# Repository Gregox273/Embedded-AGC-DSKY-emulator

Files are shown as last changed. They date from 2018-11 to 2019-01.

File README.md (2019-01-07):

# Embedded-AGC-DSKY-emulator
Apollo Block II AGC + DSKY emulator based on the virtualagc project (https://github.com/virtualagc/virtualagc).
The system is based on an STM32 32-bit ARM Cortex MCU, with custom PCB layout to match the position of buttons and lamps 
on the original DSKY.

### Repository Layout
* **agg-kicad:** submodule by Adam Greig containing useful KiCAD libraries, footprints and scripts.
* **binary_transcoder:** simple C program to rearrange binary output of the yaYUL assembler (see **virtualagc** 
submodule) into the order required for yaAGC emulator (also contained within **virtualagc**). Note that a pre-transcoded
binary file for Luminary099 is provided in the **firmware** directory.
* **ChibiOS:** ChibiOS RTOS submodule, developed by Giovanni Di Sirio.
* **firmware:** directory containing project source code.
* **gen-board.h:** submodule containing Python tool for generating ChibiOS 'board.h' header from a YAML file.
* **pcb:** directory containing project schematics and PCB design:
    * **agc-dsky:** KiCAD schematic and PCB files.
    * **agc-dsky.pretty:** Various component footprints.
    * **lib:** Various schematic symbols.
* **virtualagc:** Virtual Apollo Guidance Computer submodule. Contents include yaYUL (Apollo language assembler) and 
yaAGC (Apollo Guidance Computer emulator).

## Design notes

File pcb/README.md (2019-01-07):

# Hardware Notes
* STM32F072RBT6 48MHz microcontroller based on ARM Cortex-M0 core. 48MHz appears to be too slow to run the emulator and 
DSKY in realtime...
* MPU9250 IMU present on SPI2 bus (firmware can communicate with device but it has not yet been incorporated into the 
AGC emulation).
* Powered via Micro USB (<500mA current consumption at any time, so can be powered from e.g. a USB port on a computer).
* Microcontroller can be flashed over USB using DFU, or via Serial Wire Debug (SWD).
* TPS62132 switching regulator (5V USB to 3.3V) - high efficiency reduces overall current consumption.
* MCP23S08 SPI I/O expanders used to drive 7 segment displays in a multiplexed array.
  * Three displays are illuminated at a time, striking a balance between brightness and current consumption.
* Push buttons are multiplexed in a key matrix to reduce I/O pin usage.
* WS2812B LEDs arranged in a chain, allowing them to be driven from a single output pin. Each LED internally handles PWM
for red, green and blue channels.
  * Todo: drive LEDs using DMA instead of blocking the processor. This technique appears to be better documented on 
  STM32F3 and STM32F4 microcontrollers.
* UART port exposed (2.54mm header) to allow for future modifications/experimentation.

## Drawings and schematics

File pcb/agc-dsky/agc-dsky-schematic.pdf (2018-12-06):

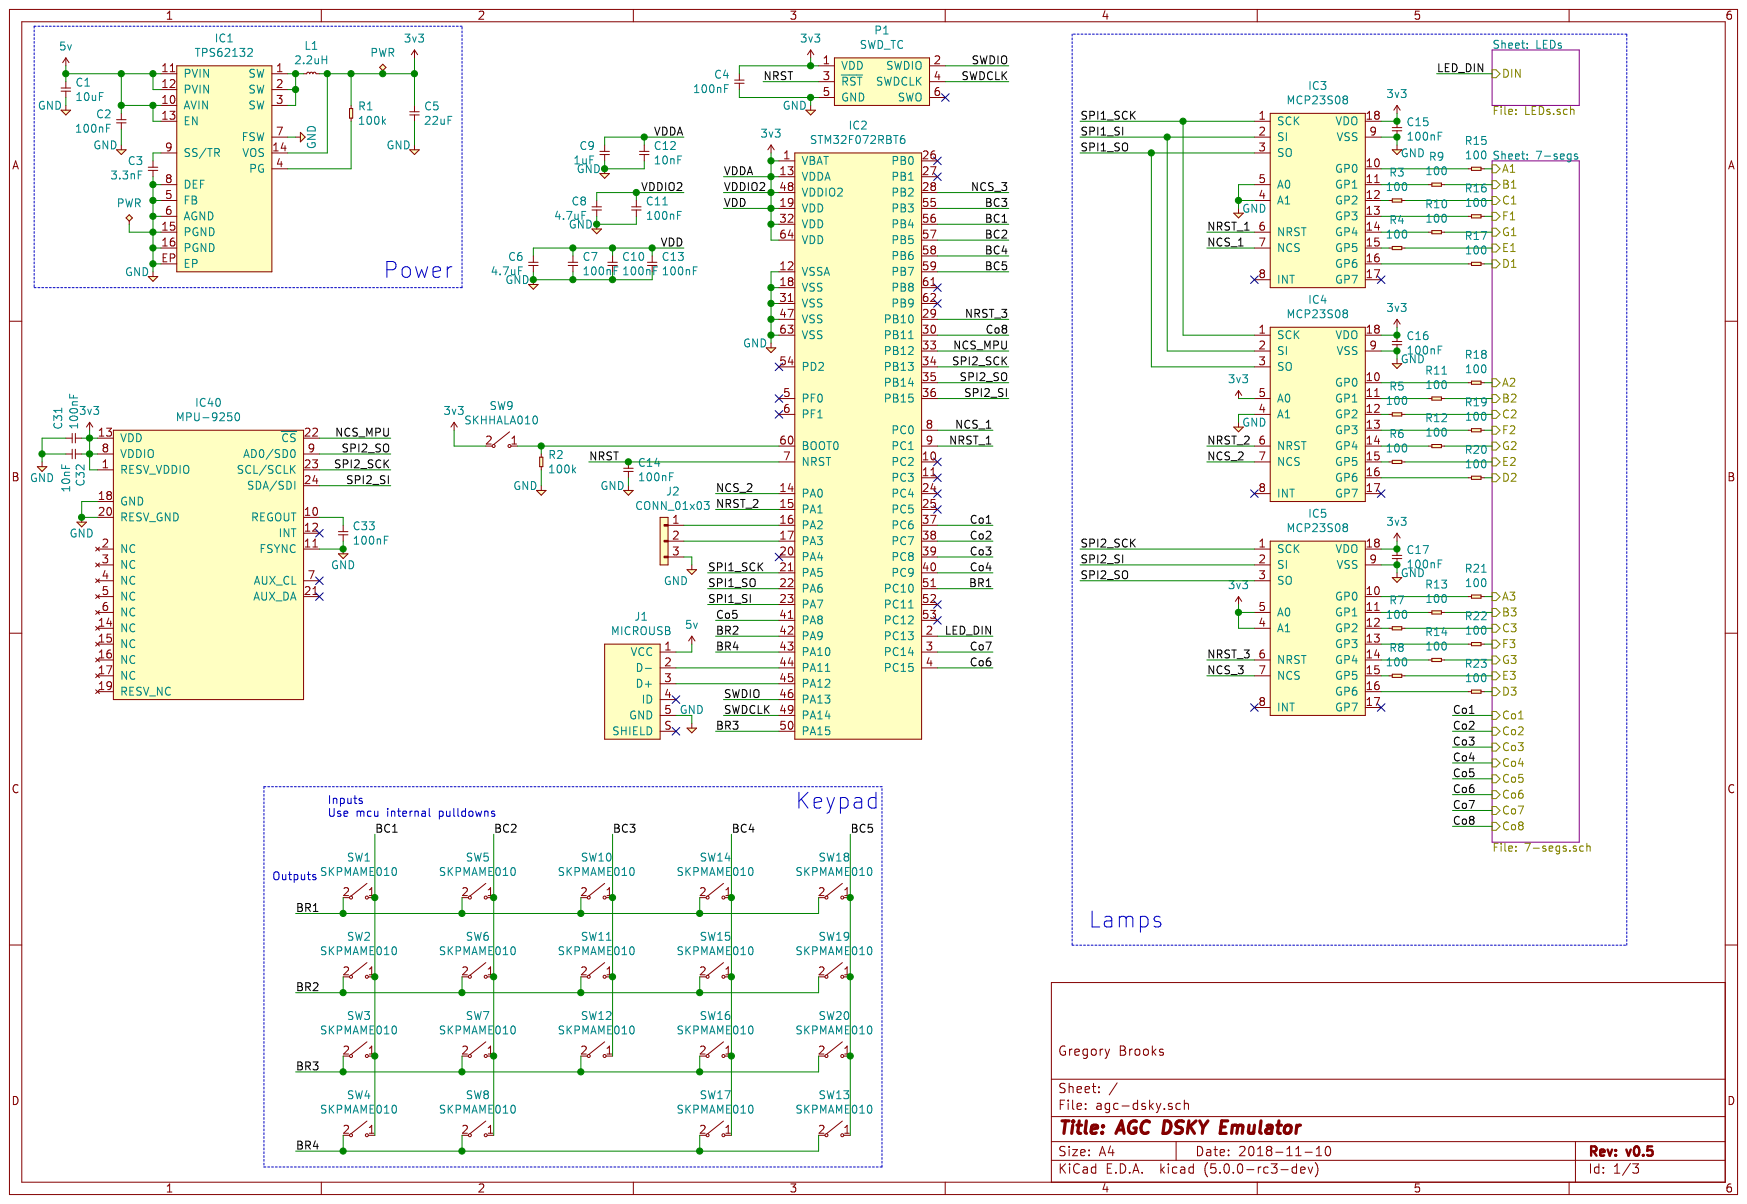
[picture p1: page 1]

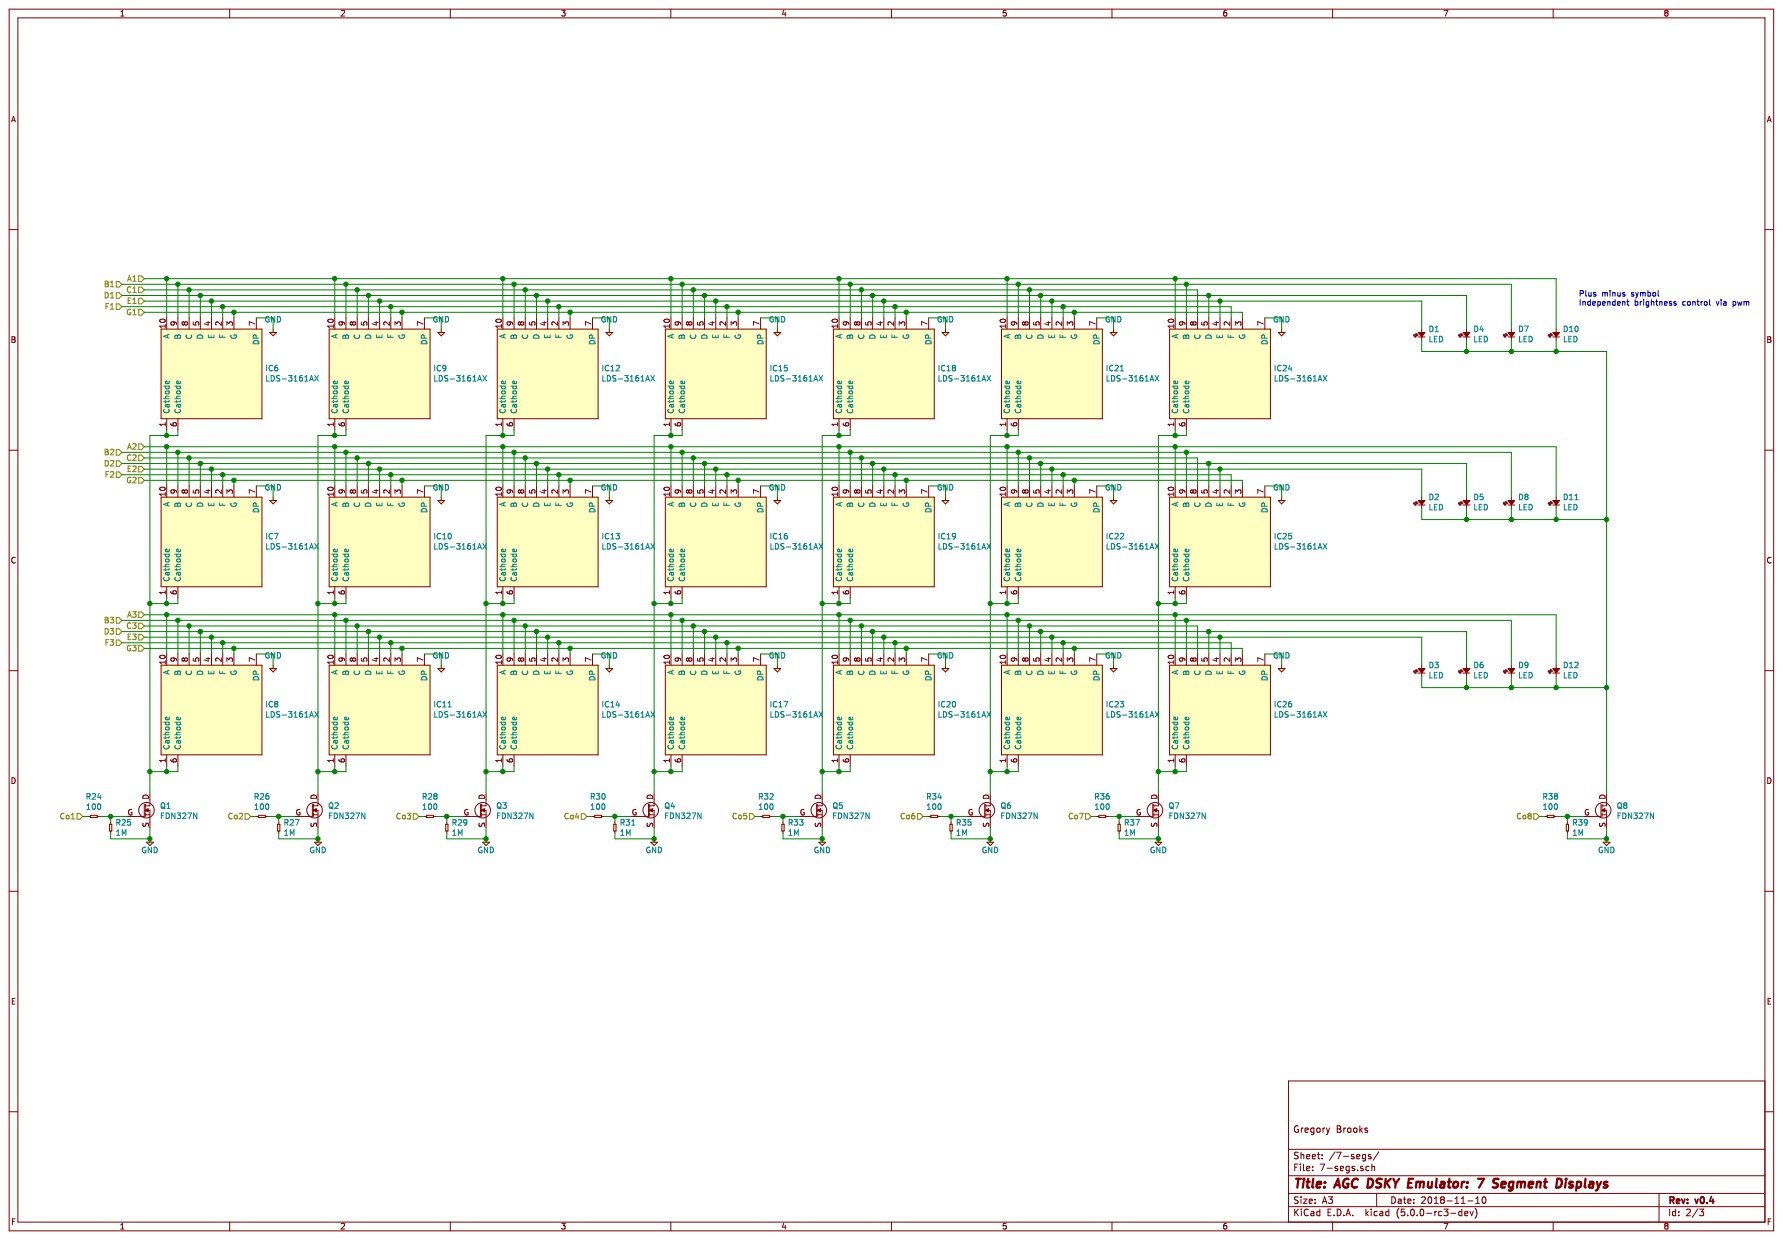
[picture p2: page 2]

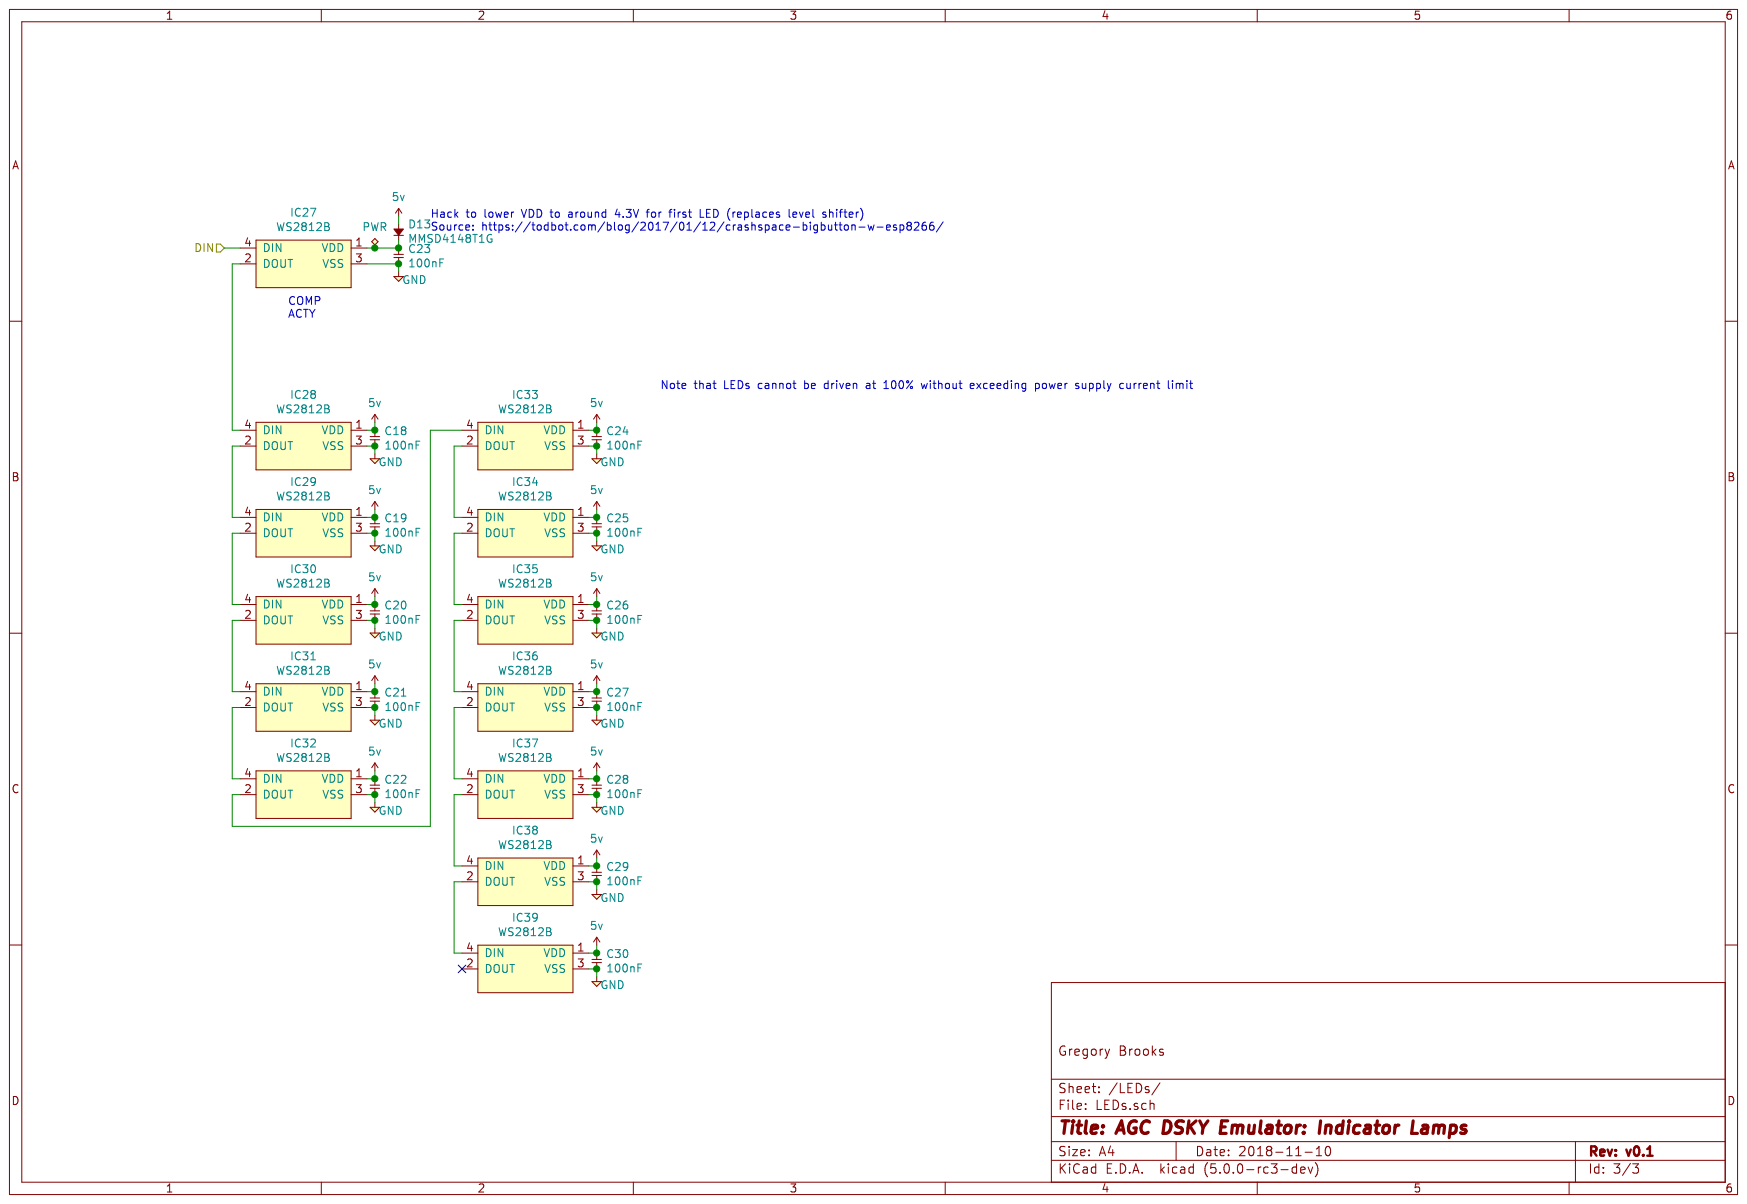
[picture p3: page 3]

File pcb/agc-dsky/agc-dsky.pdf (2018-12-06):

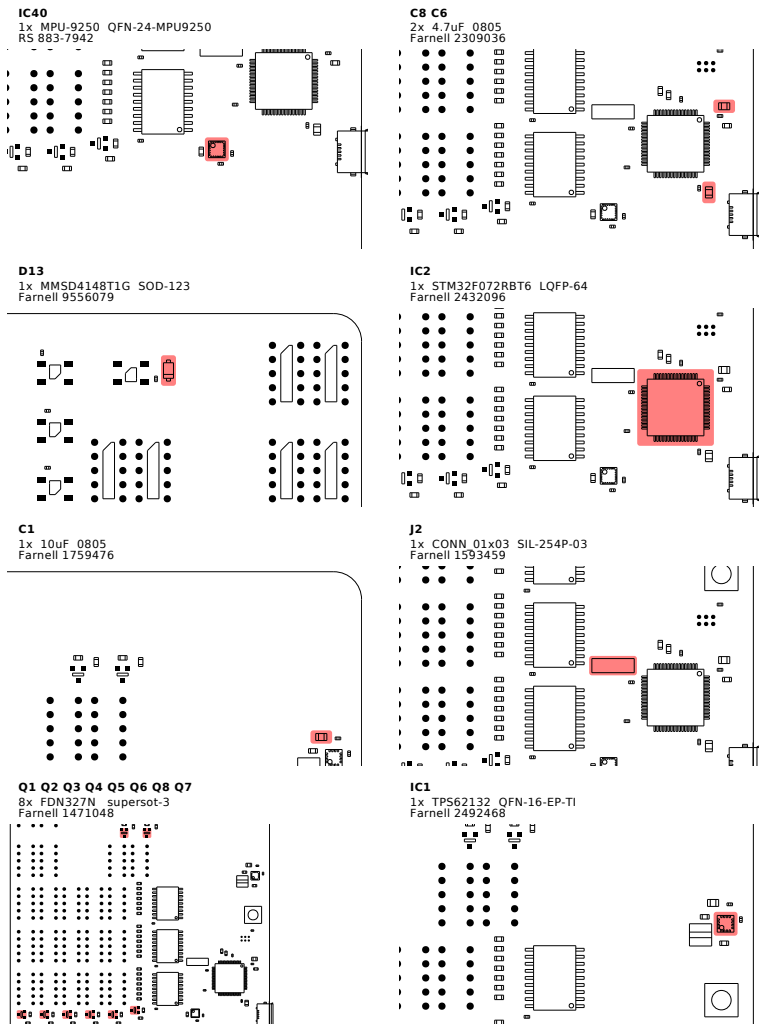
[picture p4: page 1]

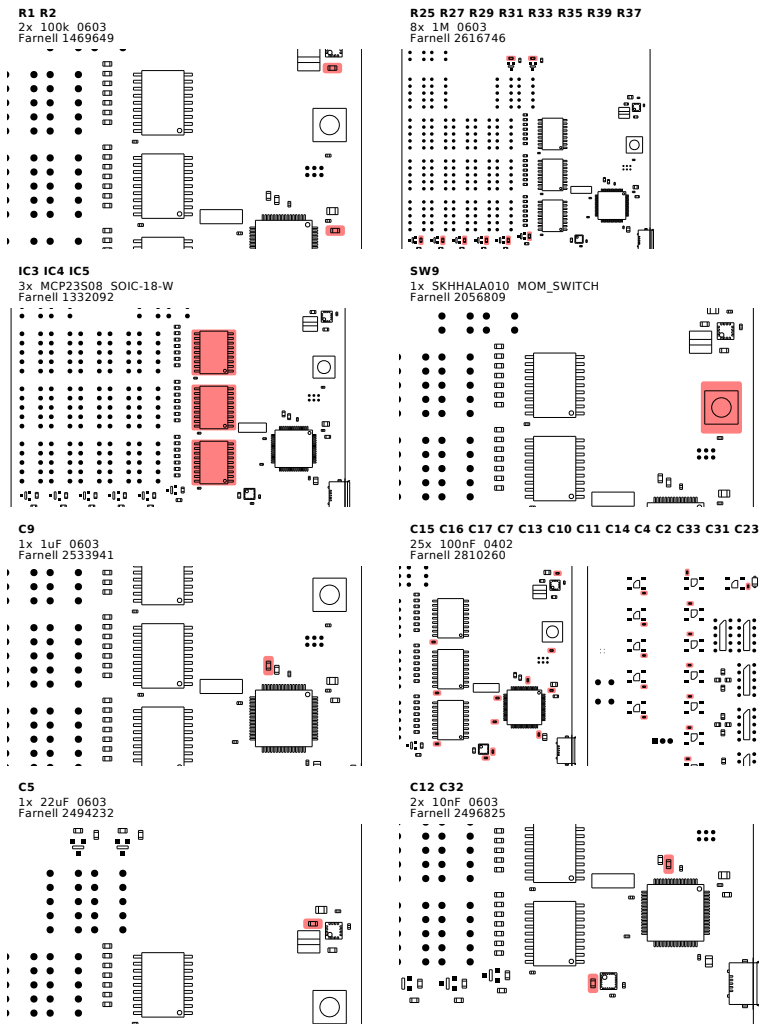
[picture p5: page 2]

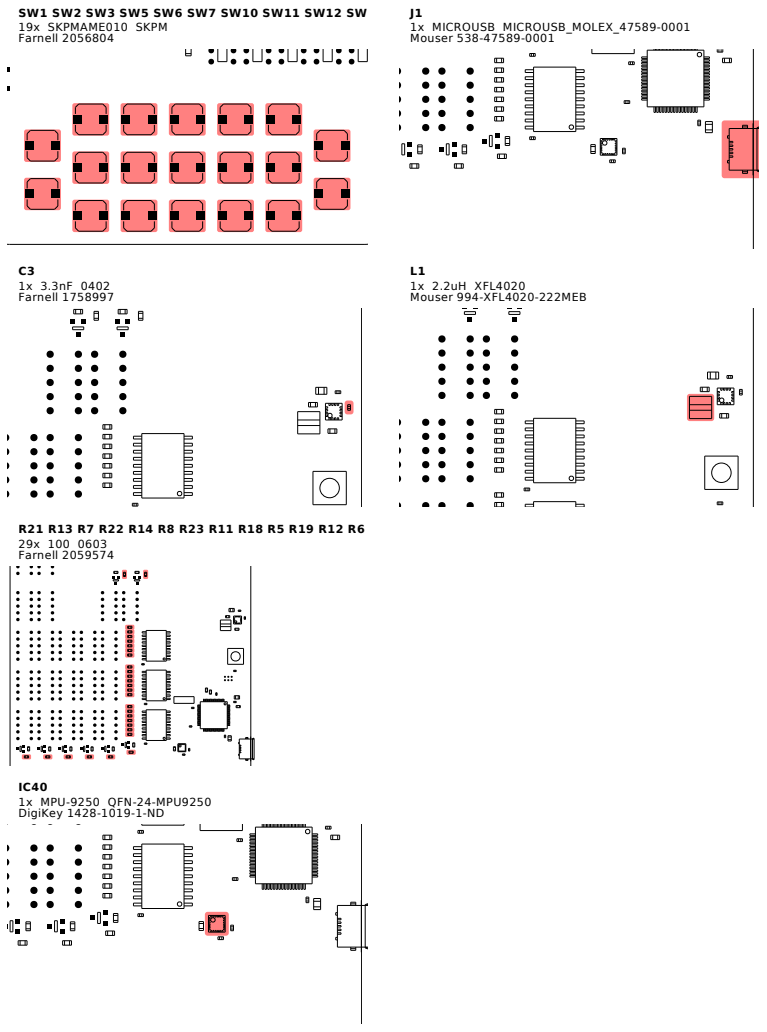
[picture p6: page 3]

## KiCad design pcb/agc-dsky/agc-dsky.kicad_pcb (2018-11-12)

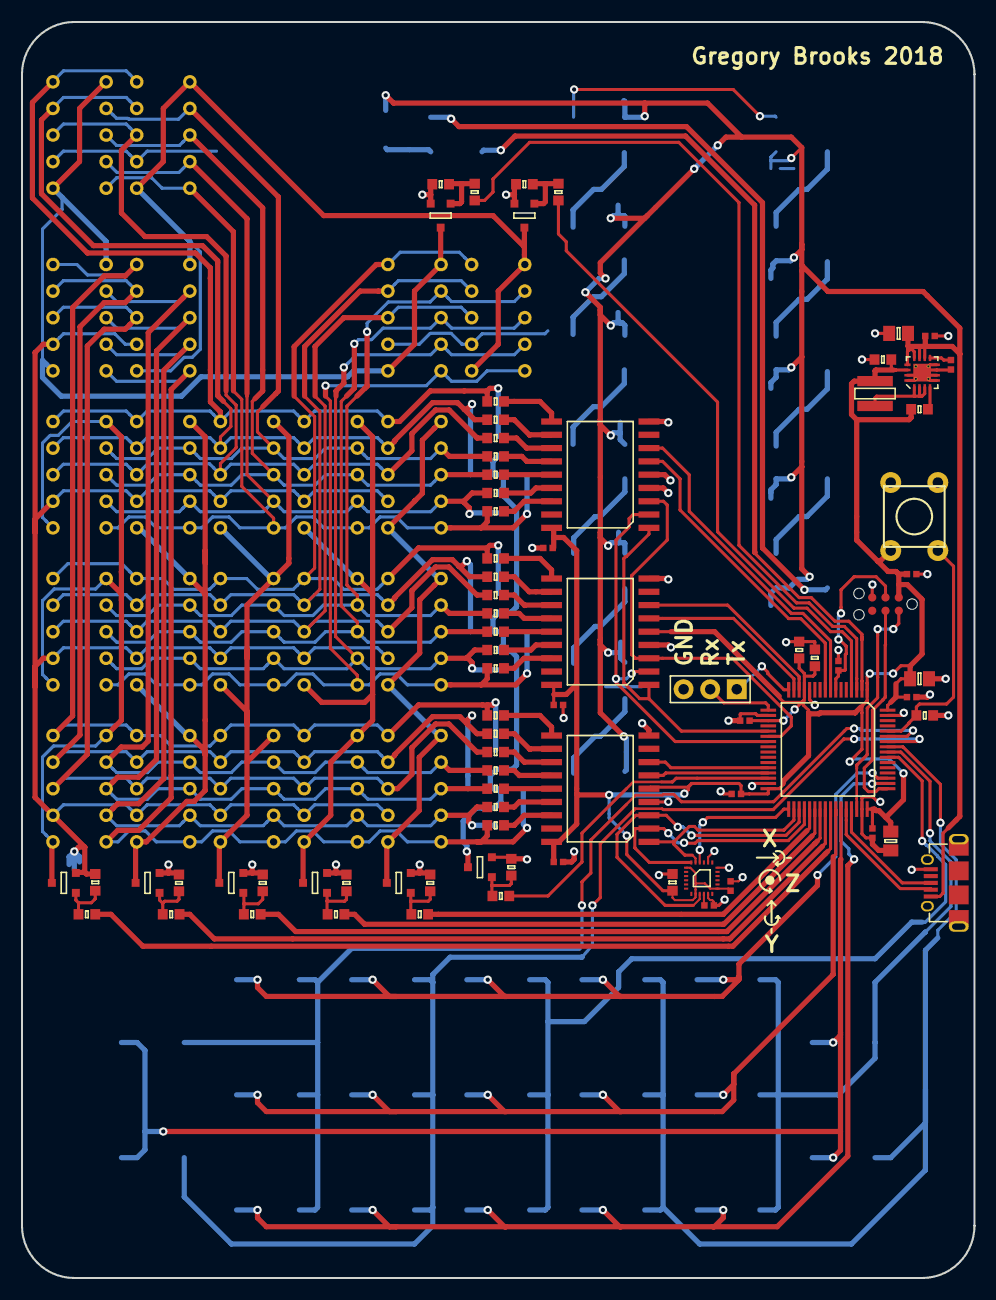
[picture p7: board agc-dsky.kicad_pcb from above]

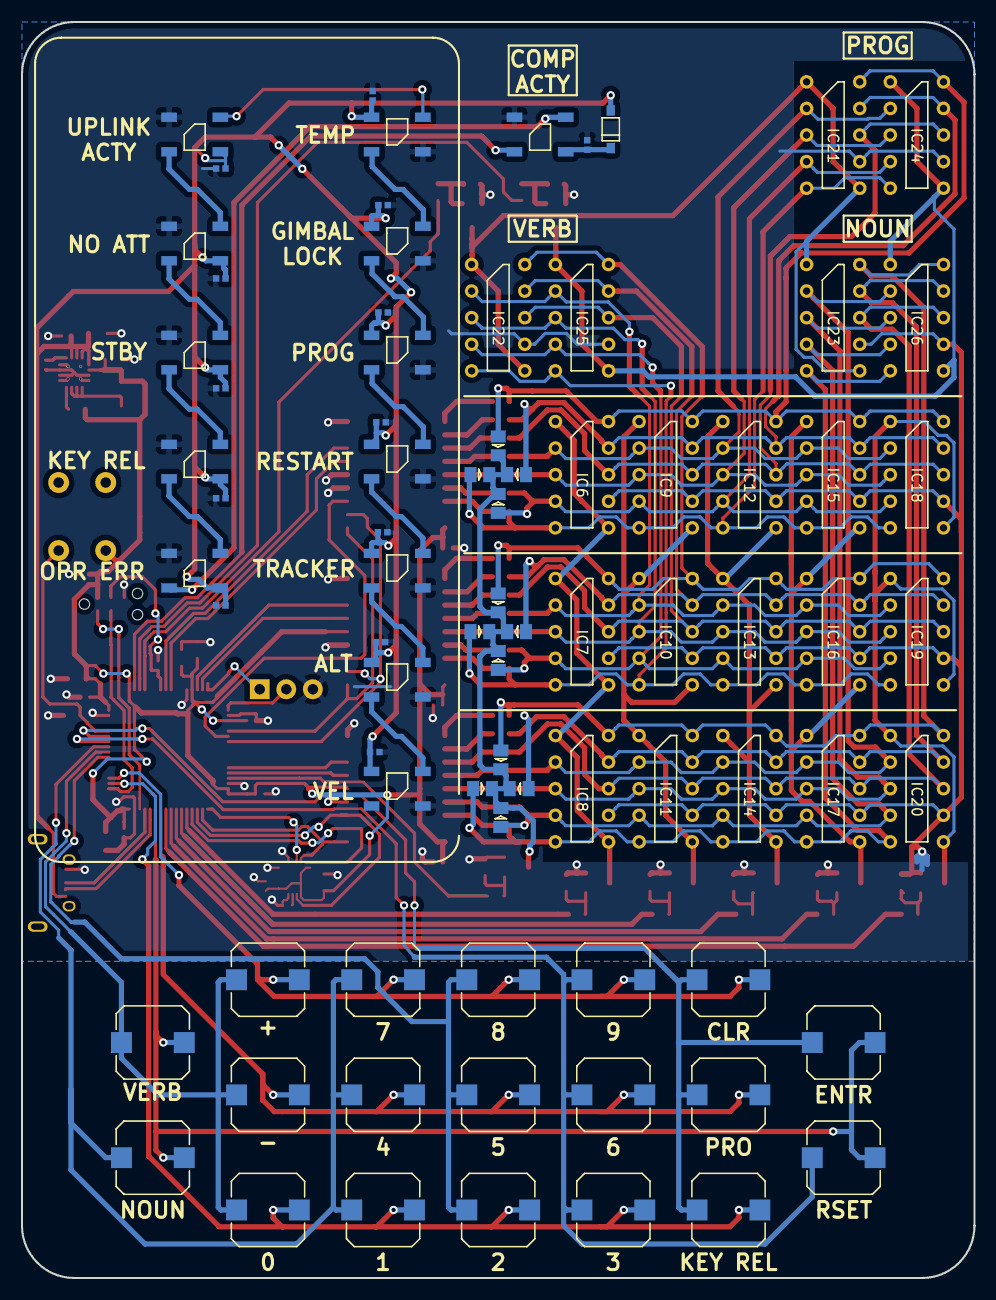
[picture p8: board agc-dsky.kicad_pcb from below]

Board: 2 copper layers, 91.0 x 120.0 mm, 157 parts (79 on the bottom side), 117 nets.

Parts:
C1: 10uF; 0805
C2, C4, C7, C10, C11, C13, C14, C15, C16, C17, C18, C19, C20, C21, C22, C23, C24, C25, C26, C27, C28, C29, C30, C31, C33: 100nF; 0402
C3: 3.3nF; 0402
C5: 22uF; 0603
C6, C8: 4.7uF; 0805
C9: 1uF; 0603
C12, C32: 10nF; 0603
D1, D2, D3, D4, D5, D6, D7, D8, D9, D10, D11, D12: LED; 0805-LED
D13: MMSD4148T1G; SOD-123
IC1: TPS62132; QFN-16-EP-TI
IC2: STM32F072RBT6; LQFP-64
IC3, IC4, IC5: MCP23S08; SOIC-18-W
IC6, IC7, IC8, IC9, IC10, IC11, IC12, IC13, IC14, IC15, IC16, IC17, IC18, IC19, IC20, IC21, IC22, IC23, IC24, IC25, IC26: LDS-3161AX
IC27, IC28, IC29, IC30, IC31, IC32, IC33, IC34, IC35, IC36, IC37, IC38, IC39: WS2812B
IC40: MPU-9250; QFN-24-MPU9250
J1: MICROUSB; MICROUSB_MOLEX_47589-0001
J2: CONN_01x03; SIL-254P-03
L1: 2.2uH; XFL4020
P1: SWD_TC; TC2030-NL
Q1, Q2, Q3, Q4, Q5, Q6, Q7, Q8: FDN327N; supersot-3
R1, R2: 100k; 0603
R3, R4, R5, R6, R7, R8, R9, R10, R11, R12, R13, R14, R15, R16, R17, R18, R19, R20, R21, R22, R23, R24, R26, R28, R30, R32, R34, R36, R38: 100; 0603
R25, R27, R29, R31, R33, R35, R37, R39: 1M; 0603
SW1, SW2, SW3, SW4, SW5, SW6, SW7, SW8, SW10, SW11, SW12, SW13, SW14, SW15, SW16, SW17, SW18, SW19, SW20: SKPMAME010; SKPM
SW9: SKHHALA010; MOM_SWITCH

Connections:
3v3: C4.1, C5.1, C6.1, C7.1, C8.1, C9.1, C10.1, C11.1, C12.1, C13.1, C15.1, C16.1, C17.1, C31.2, C32.1, IC1.14, IC2.1, IC2.13, IC2.19, IC2.32, IC2.48, IC2.64, IC3.18, IC4.5, IC4.18, IC5.4, IC5.5, IC5.18, IC40.1, IC40.8, IC40.13, L1.2, P1.1, R1.1, SW9.2
5v: C1.1, C2.1, C18.1, C19.1, C20.1, C21.1, C22.1, C24.1, C25.1, C26.1, C27.1, C28.1, C29.1, C30.1, D13.2, IC1.10, IC1.11, IC1.12, IC1.13, IC28.1, IC29.1, IC30.1, IC31.1, IC32.1, IC33.1, IC34.1, IC35.1, IC36.1, IC37.1, IC38.1, IC39.1, J1.1
/7-segs/A1: D10.2, IC6.10, IC9.10, IC12.10, IC15.10, IC18.10, IC21.10, IC24.10, R15.2
/7-segs/A2: D11.2, IC7.10, IC10.10, IC13.10, IC16.10, IC19.10, IC22.10, IC25.10, R18.2
/7-segs/A3: D12.2, IC8.10, IC11.10, IC14.10, IC17.10, IC20.10, IC23.10, IC26.10, R21.2
/7-segs/B1: D7.2, IC6.9, IC9.9, IC12.9, IC15.9, IC18.9, IC21.9, IC24.9, R9.2
/7-segs/B2: D8.2, IC7.9, IC10.9, IC13.9, IC16.9, IC19.9, IC22.9, IC25.9, R11.2
/7-segs/B3: D9.2, IC8.9, IC11.9, IC14.9, IC17.9, IC20.9, IC23.9, IC26.9, R13.2
/7-segs/C1: IC6.8, IC9.8, IC12.8, IC15.8, IC18.8, IC21.8, IC24.8, R3.2
/7-segs/C2: IC7.8, IC10.8, IC13.8, IC16.8, IC19.8, IC22.8, IC25.8, R5.2
/7-segs/C3: IC8.8, IC11.8, IC14.8, IC17.8, IC20.8, IC23.8, IC26.8, R7.2
/7-segs/D1: D4.2, IC6.5, IC9.5, IC12.5, IC15.5, IC18.5, IC21.5, IC24.5, R17.2
/7-segs/D2: D5.2, IC7.5, IC10.5, IC13.5, IC16.5, IC19.5, IC22.5, IC25.5, R20.2
/7-segs/D3: D6.2, IC8.5, IC11.5, IC14.5, IC17.5, IC20.5, IC23.5, IC26.5, R23.2
/7-segs/E1: D1.2, IC6.4, IC9.4, IC12.4, IC15.4, IC18.4, IC21.4, IC24.4, R4.2
/7-segs/E2: D2.2, IC7.4, IC10.4, IC13.4, IC16.4, IC19.4, IC22.4, IC25.4, R6.2
/7-segs/E3: D3.2, IC8.4, IC11.4, IC14.4, IC17.4, IC20.4, IC23.4, IC26.4, R8.2
/7-segs/F1: IC6.2, IC9.2, IC12.2, IC15.2, IC18.2, IC21.2, IC24.2, R16.2
/7-segs/F2: IC7.2, IC10.2, IC13.2, IC16.2, IC19.2, IC22.2, IC25.2, R19.2
/7-segs/F3: IC8.2, IC11.2, IC14.2, IC17.2, IC20.2, IC23.2, IC26.2, R22.2
/7-segs/G1: IC6.3, IC9.3, IC12.3, IC15.3, IC18.3, IC21.3, IC24.3, R10.2
/7-segs/G2: IC7.3, IC10.3, IC13.3, IC16.3, IC19.3, IC22.3, IC25.3, R12.2
/7-segs/G3: IC8.3, IC11.3, IC14.3, IC17.3, IC20.3, IC23.3, IC26.3, R14.2
/BC1: IC2.56, SW1.1, SW2.1, SW3.1, SW4.1
/BC2: IC2.57, SW5.1, SW6.1, SW7.1, SW8.1
/BC3: IC2.55, SW10.1, SW11.1, SW12.1
/BC4: IC2.58, SW14.1, SW15.1, SW16.1, SW17.1
/BC5: IC2.59, SW13.1, SW18.1, SW19.1, SW20.1
/BR1: IC2.51, SW1.2, SW5.2, SW10.2, SW14.2, SW18.2
/BR2: IC2.42, SW2.2, SW6.2, SW11.2, SW15.2, SW19.2
/BR3: IC2.50, SW3.2, SW7.2, SW12.2, SW16.2, SW20.2
/BR4: IC2.43, SW4.2, SW8.2, SW13.2, SW17.2
/Co1: IC2.37, R24.1
/Co2: IC2.38, R26.1
/Co3: IC2.39, R28.1
/Co4: IC2.40, R30.1
/Co5: IC2.41, R32.1
/Co6: IC2.4, R34.1
/Co7: IC2.3, R36.1
/Co8: IC2.30, R38.1
/LED_DIN: IC2.2, IC27.4
/NCS_1: IC2.8, IC3.7
/NCS_2: IC2.14, IC4.7
/NCS_3: IC2.28, IC5.7
/NCS_MPU: IC2.33, IC40.22
/NRST: C14.1, IC2.7, P1.3
/NRST_1: IC2.9, IC3.6
/NRST_2: IC2.15, IC4.6
/NRST_3: IC2.29, IC5.6
/SPI1_SCK: IC2.21, IC3.1, IC4.1
/SPI1_SI: IC2.23, IC3.2, IC4.2
/SPI1_SO: IC2.22, IC3.3, IC4.3
/SPI2_SCK: IC2.34, IC5.1, IC40.23
/SPI2_SI: IC2.36, IC5.2, IC40.24
/SPI2_SO: IC2.35, IC5.3, IC40.9
/SWDCLK: IC2.49, P1.4
/SWDIO: IC2.46, P1.2
GND: C1.2, C2.2, C3.1, C4.2, C5.2, C6.2, C7.2, C8.2, C9.2, C10.2, C11.2, C12.2, C13.2, C14.2, C15.2, C16.2, C17.2, C18.2, C19.2, C20.2, C21.2, C22.2, C23.2, C24.2, C25.2, C26.2, C27.2, C28.2, C29.2, C30.2, C31.1, C32.2, C33.2, IC1.5, IC1.6, IC1.7, IC1.8, IC1.15, IC1.16, IC1.EP, IC2.12, IC2.18, IC2.31, IC2.47, IC2.63, IC3.4, IC3.5, IC3.9, IC4.4, IC4.9, IC5.9, IC6.7, IC7.7, IC8.7, IC9.7, IC10.7, IC11.7, IC12.7, IC13.7, IC14.7, IC15.7, IC16.7, IC17.7, IC18.7, IC19.7, IC20.7, IC21.7, IC22.7, IC23.7, IC24.7, IC25.7, IC26.7, IC27.3, IC28.3, IC29.3, IC30.3, IC31.3, IC32.3, IC33.3, IC34.3, IC35.3, IC36.3, IC37.3, IC38.3, IC39.3, IC40.11, IC40.18, IC40.20, J1.5, J2.3, P1.5, Q1.S, Q2.S, Q3.S, Q4.S, Q5.S, Q6.S, Q7.S, Q8.S, R2.2, R25.2, R27.2, R29.2, R31.2, R33.2, R35.2, R37.2, R39.2
unnamed: C3.2, IC1.9
unnamed: C23.1, D13.1, IC27.1
unnamed: C33.1, IC40.10
unnamed: D1.1, D2.1, D3.1, D4.1, D5.1, D6.1, D7.1, D8.1, D9.1, D10.1, D11.1, D12.1, Q8.D
unnamed: IC1.1, IC1.2, IC1.3, L1.1
unnamed: IC1.4, R1.2
unnamed: IC2.16, J2.1
unnamed: IC2.17, J2.2
unnamed: IC2.44, J1.2
unnamed: IC2.45, J1.3
unnamed: IC2.60, R2.1, SW9.1
unnamed: IC3.10, R15.1
unnamed: IC3.11, R9.1
unnamed: IC3.12, R3.1
unnamed: IC3.13, R16.1
unnamed: IC3.14, R10.1
unnamed: IC3.15, R4.1
unnamed: IC3.16, R17.1
unnamed: IC4.10, R18.1
unnamed: IC4.11, R11.1
unnamed: IC4.12, R5.1
unnamed: IC4.13, R19.1
unnamed: IC4.14, R12.1
unnamed: IC4.15, R6.1
unnamed: IC4.16, R20.1
unnamed: IC5.10, R21.1
unnamed: IC5.11, R13.1
unnamed: IC5.12, R7.1
unnamed: IC5.13, R22.1
unnamed: IC5.14, R14.1
unnamed: IC5.15, R8.1
unnamed: IC5.16, R23.1
unnamed: IC6.1, IC6.6, IC7.1, IC7.6, IC8.1, IC8.6, Q1.D
unnamed: IC9.1, IC9.6, IC10.1, IC10.6, IC11.1, IC11.6, Q2.D
unnamed: IC12.1, IC12.6, IC13.1, IC13.6, IC14.1, IC14.6, Q3.D
unnamed: IC15.1, IC15.6, IC16.1, IC16.6, IC17.1, IC17.6, Q4.D
unnamed: IC18.1, IC18.6, IC19.1, IC19.6, IC20.1, IC20.6, Q5.D
unnamed: IC21.1, IC21.6, IC22.1, IC22.6, IC23.1, IC23.6, Q6.D
unnamed: IC24.1, IC24.6, IC25.1, IC25.6, IC26.1, IC26.6, Q7.D
unnamed: IC27.2, IC28.4
unnamed: IC28.2, IC29.4
unnamed: IC29.2, IC30.4
unnamed: IC30.2, IC31.4
unnamed: IC31.2, IC32.4
unnamed: IC32.2, IC33.4
unnamed: IC33.2, IC34.4
unnamed: IC34.2, IC35.4
unnamed: IC35.2, IC36.4
unnamed: IC36.2, IC37.4
unnamed: IC37.2, IC38.4
unnamed: IC38.2, IC39.4
unnamed: Q1.G, R24.2, R25.1
unnamed: Q2.G, R26.2, R27.1
unnamed: Q3.G, R28.2, R29.1
unnamed: Q4.G, R30.2, R31.1
unnamed: Q5.G, R32.2, R33.1
unnamed: Q6.G, R34.2, R35.1
unnamed: Q7.G, R36.2, R37.1
unnamed: Q8.G, R38.2, R39.1

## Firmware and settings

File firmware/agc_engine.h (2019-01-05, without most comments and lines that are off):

#ifndef AGC_SOCKET_ENABLED
#ifdef __cplusplus
extern "C" {
#endif
#define AGC_ENGINE_H
#define NULL ((void *) 0)
#ifdef WIN32
typedef short int16_t;
typedef signed char int8_t;
typedef unsigned char uint8_t; // 20170326
typedef unsigned int uint32_t; // 20170326
typedef unsigned short uint16_t; // 20170329
#ifdef __MINGW32__
typedef unsigned long long uint64_t;
#else
typedef unsigned __int64 uint64_t;
#endif
#elif defined (__embedded__)
#include <stdint.h>
#elif defined (SDCC)
typedef int int16_t;
typedef signed char int8_t;
typedef unsigned uint16_t;
extern long random (void);
#else // WIN32
#include <stdint.h>
#endif // WIN32
#ifdef WIN32
#define SOCKET_BROKEN 1
#else
#define SOCKET_ERROR -1
#define SOCKET_BROKEN (errno == EPIPE)
#endif
#define MAX_SYM_DUMP 25
#define MAX_FILE_DUMP 25
#define AGC_PER_SECOND ((1024000 + 6) / 12)
#define REG16 3
#define RegA 00
#define RegL 01
#define RegQ 02
#define RegEB 03
#define RegFB 04
#define RegZ 05
#define RegBB 06
#define RegZERO 07
#define RegARUPT 010
#define RegLRUPT 011
#define RegQRUPT 012
#define RegZRUPT 015
#define RegBBRUPT 016
#define RegBRUPT 017
#define RegCYR 020
#define RegSR 021
#define RegCYL 022
#define RegEDOP 023
#define RegCOUNTER 024
#define RegTIME2 024
#define RegTIME1 025
#define RegTIME3 026
#define RegTIME4 027
#define RegTIME5 030
#define RegTIME6 031
#define RegCDUX 032
#define RegCDUY 033
#define RegCDUZ 034
#define RegOPTY 035
#define RegOPTX 036
#define RegPIPAX 037
#define RegPIPAY 040
#define RegPIPAZ 041
#define RegRHCP 042
#define RegRHCY 043
#define RegRHCR 044
#define RegINLINK 045
#define RegRNRAD 046
#define RegGYROCTR 047
#define RegCDUXCMD 050
#define RegCDUYCMD 051
#define RegCDUZCMD 052
#define RegOPTYCMD 053
#define RegOPTXCMD 054
#define RegOUTLINK 057
#define RegALTM 060
#define RegRAM 060
#define RegCORE 04000
#define RegEND 0120000
#define NUM_CHANNELS 512
#define ChanSCALER2 03
#define ChanSCALER1 04
#define ChanS 07
#define CH77_PARITY_FAIL    000001
#define CH77_TC_TRAP        000004
#define CH77_RUPT_LOCK      000010
#define CH77_NIGHT_WATCHMAN 000020
#define DSKY_AGC_WARN 000001
#define DSKY_TEMP     000010
#define DSKY_KEY_REL  000020
#define DSKY_VN_FLASH 000040
#define DSKY_OPER_ERR 000100
#define DSKY_RESTART  000200
#define DSKY_STBY     000400
#define DSKY_EL_OFF   001000
#define NUM_INTERRUPT_TYPES 10
#define MAX_DOWNLINK_LIST 260
#define DEFAULT_SWIDTH 79
#define DEFAULT_SHEIGHT 42
#define SWIDTH 160
#define SHEIGHT 100
#define DL_CM_POWERED_LIST 0
#define DL_LM_ORBITAL_MANEUVERS 1
#define DL_CM_COAST_ALIGN 2
#define DL_LM_COAST_ALIGN 3
#define DL_CM_RENDEZVOUS_PRETHRUST 4
#define DL_LM_RENDEZVOUS_PRETHRUST 5
#define DL_CM_PROGRAM_22 6
#define DL_LM_DESCENT_ASCENT 7
#define DL_LM_LUNAR_SURFACE_ALIGN 8
#define DL_CM_ENTRY_UPDATE 9
#define DL_LM_AGS_INITIALIZATION_UPDATE 10
typedef enum {
  FMT_SP, FMT_DP, FMT_OCT, FMT_2OCT, FMT_DEC, FMT_2DEC, FMT_USP
} Format_t;
typedef void Swrite_t (void);
typedef char *Sformat_t (int IndexIntoList, int Scale, Format_t Format);
typedef struct {
  int IndexIntoList;	// if -1, then is a spacer.
  char Name[65];
  int Scale;
  Format_t Format;
  Sformat_t *Formatter;
  int Row;		// If 0,0, then just "next" position.
  int Col;
} FieldSpec_t;
typedef struct {
  char Title[SWIDTH + 1];
  FieldSpec_t FieldSpecs[MAX_DOWNLINK_LIST];
} DownlinkListSpec_t;
typedef void ProcessDownlinkList_t (const DownlinkListSpec_t *Spec);
typedef struct
{
  uint64_t  CycleCounter;
  int16_t Erasable[8][0400];	// Banks 0,1,2 are "unswitched erasable".
  uint32_t Parities[40*(02000/32)];
  int16_t InputChannel[NUM_CHANNELS];
  int16_t OutputChannel7;
  int16_t OutputChannel10[16];
  int16_t IndexValue;
  int8_t InterruptRequests[1 + NUM_INTERRUPT_TYPES];	// 0-index not used.
  unsigned ExtraCode:1;		// Set by the "Extend" instruction.
  unsigned AllowInterrupt:1;
  unsigned InIsr:1;		// Set when in an ISR, reset when in normal code.
  unsigned SubstituteInstruction:1;	// Use BBRUPT register.
  unsigned PendFlag:1;		// Multi-MCT instruction pending.
  unsigned PendDelay:3;		// Countdown to pending instruction.
  unsigned ExtraDelay:3;	// ... and extra, for special cases.
  unsigned DownruptTimeValid:1;	// Set if the DownruptTime field is valid.
  unsigned NightWatchman:1;     // Set when Night Watchman is watching. Cleared by accessing address 67.
  unsigned NightWatchmanTripped:1; // Set when Night Watchman has been tripped and its CH77 bit is being asserted.
  unsigned RuptLock:1;          // Set when rupts are being watched. Cleared by executing any non-ISR instruction
  unsigned NoRupt:1;            // Set when rupts are being watched. Cleared by executing any ISR instruction
  unsigned TCTrap:1;            // Set when TC is being watched. Cleared by executing any non-TC/TCF instruction
  unsigned NoTC:1;              // Set when TC is being watched. Cleared by executing TC or TCF
  unsigned Standby:1;           // Set while the computer is in standby mode.
  unsigned SbyPressed:1;        // Set while PRO is being held down; cleared by releasing PRO
  unsigned SbyStillPressed:1;   // Set upon entry to standby, until PRO is released
  unsigned ParityFail:1;        // Set when a parity failure is encountered accessing memory (in yaAGC, just hitting banks 44+)
  unsigned CheckParity:1;       // Enable parity checking for fixed memory.
  unsigned RestartLight:1;      // The present state of the RESTART light
  unsigned TookBZF:1;           // Flag for having just taken a BZF branch, used for simulation of a TC Trap hardware bug
  unsigned TookBZMF:1;          // Flag for having just taken a BZMF branch, used for simulation of a TC Trap hardware bug
  unsigned GeneratedWarning:1;  // Whether there is a pending input to the warning filter
  unsigned Trap31A:1;           // Enable flag for Trap 31A
  unsigned Trap31B:1;           // Enable flag for Trap 31B
  unsigned Trap32:1;            // Enable flag for Trap 32
  uint32_t WarningFilter;       // Current voltage of the AGC warning filter
  uint64_t  DownruptTime;	// Time when next DOWNRUPT occurs.
  int Downlink;
  int NextZ;                    // Next value for the Z register
  int ScalerCounter;            // Counter to keep track of scaler increment timing
  int ChannelRoutineCount;      // Counter to keep track of channel interface routine timing
  unsigned DskyTimer;           // Timer for DSKY-related timing
  unsigned DskyFlash;           // DSKY flash counter (0 = flash occurring)
  unsigned DskyChannel163;      // Copy of the fake DSKY channel 163
  void *agc_clientdata;
} agc_t;
#define MAX_DEBUG_RULES 256
typedef struct
{
  int KeyCode;
  int Channel;
  int Value;
  char Logic;
} DebugRule_t;
#ifdef AGC_ENGINE_C
int DebugDsky = 0;
int InhibitAlarms = 0;
int NumDebugRules = 0;
DebugRule_t DebugRules[MAX_DEBUG_RULES];
#else
extern int DebugDsky;
extern int InhibitAlarms;
extern int NumDebugRules;
extern DebugRule_t DebugRules[MAX_DEBUG_RULES];
extern int initializeSunburst37;
#endif
#define MAX_BACKTRACE_POINTS 100
#define BACKTRACES_PER_LINE 5
typedef struct {
  uint64_t  CycleCounter;
  int16_t Erasable[8][0400];	// Banks 0,1,2 are "unswitched erasable".
  int16_t InputChannel[NUM_CHANNELS];
  int16_t OutputChannel7;
  int16_t OutputChannel10[16];
  int16_t IndexValue;
  int8_t InterruptRequests[1 + NUM_INTERRUPT_TYPES];
  int8_t DueToInterrupt;	// Indicates interrupt type causing jump (0 if not).
  unsigned ExtraCode:1;		// Set by the "Extend" instruction.
  unsigned AllowInterrupt:1;	// Set when interrupts are enabled.
  unsigned InIsr:1;		// Set when in an ISR, reset when in normal code.
  unsigned SubstituteInstruction:1;	// Use BBRUPT register.
} BacktracePoint_t;
typedef struct
{
  int Socket;
  unsigned char Packet[4];
  int Size;
  int ChannelMasks[256];
} Client_t;
#define DEFAULT_MAX_CLIENTS 10
#ifdef AGC_ENGINE_C
int DebugMode = 0;
int SingleStepCounter = -2;		// -2 when not in --debug mode.
int BacktraceInitialized = 0;		// Becomes -1 on error.
BacktracePoint_t *BacktracePoints = NULL;
int BacktraceNextAdd = 0;
int BacktraceCount = 0;
int MAX_CLIENTS = DEFAULT_MAX_CLIENTS;
static Client_t DefaultClients[DEFAULT_MAX_CLIENTS];
static int DefaultSockets[DEFAULT_MAX_CLIENTS];
Client_t *Clients = DefaultClients;
int *ServerSockets = DefaultSockets;
int NumServers = 0;
int SocketInterlaceReload = 50;
int DebugDeda = 0, DedaQuiet = 0;
int DedaMonitor = 0;
int DedaAddress;
uint64_t  DedaWhen;
int DownlinkListBuffer[MAX_DOWNLINK_LIST];
int DownlinkListCount = 0, DownlinkListExpected = 0, DownlinkListZero = -1;
ProcessDownlinkList_t *ProcessDownlinkList = NULL;
int CmOrLm = 0;	// Default is 0 (LM); other choice is 1 (CM)
char Sbuffer[SHEIGHT][SWIDTH + 1];
int Sheight = DEFAULT_SHEIGHT, Swidth = DEFAULT_SWIDTH;
int LastRhcPitch = 0, LastRhcYaw = 0, LastRhcRoll = 0;
#else //AGC_ENGINE_C
extern int DebugMode;
extern int SingleStepCounter;
extern int BacktraceInitialized;
extern BacktracePoint_t *BacktracePoints;
extern int BacktraceNextAdd;
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

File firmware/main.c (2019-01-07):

/*
  	File modified by Gregory Brooks 2018
  	(based on ChibiOS STM32F072RBT6 demo)

    ChibiOS - Copyright (C) 2006..2018 Giovanni Di Sirio

    Licensed under the Apache License, Version 2.0 (the "License");
    you may not use this file except in compliance with the License.
    You may obtain a copy of the License at

        http://www.apache.org/licenses/LICENSE-2.0

    Unless required by applicable law or agreed to in writing, software
    distributed under the License is distributed on an "AS IS" BASIS,
    WITHOUT WARRANTIES OR CONDITIONS OF ANY KIND, either express or implied.
    See the License for the specific language governing permissions and
    limitations under the License.
*/
#include <string.h>
#include "ch.h"
#include "hal.h"
#include "buttons.h"
#include "displays.h"
#include "lamps.h"

#include "yaAGC.h"
#include "agc_engine.h"
#include "agc_symtab.h"

//#define TEST

static agc_t *State;
thread_reference_t main_thread_ref = NULL;

void test_buttons(void)
{
  uint8_t row, col;
  for(uint8_t i = 0; i < NUM_BUTTONS; i++)
  {
    if(buttons_get_state_id(i))
    {
      button_row_col(i, &row, &col);
      displays_set_line(0, row);
      displays_set_line(1, col);
      return; // Only show first pressed button
    }
  }
}

void agc_init(agc_t *State)
{
  State->CheckParity = 0;
  memset(&State->Parities, 0, sizeof(State->Parities));

  // Clear i/o channels.
  for (int i = 0; i < NUM_CHANNELS; i++)
    State->InputChannel[i] = 0;
  State->InputChannel[030] = 037777;
  State->InputChannel[031] = 077777;
  State->InputChannel[032] = 077777;
  State->InputChannel[033] = 077777;

  // Clear erasable memory.
  for (int Bank = 0; Bank < 8; Bank++)
    for (int j = 0; j < 0400; j++)
      State->Erasable[Bank][j] = 0;
  State->Erasable[0][RegZ] = 04000;	// Initial program counter.

  // Set up the CPU state variables that aren't part of normal memory.
  State->CycleCounter = 0;
  State->ExtraCode = 0;
  State->AllowInterrupt = 1; // The GOJAM sequence enables interrupts
  State->InterruptRequests[8] = 1;	// DOWNRUPT.
  //State->RegA16 = 0;
  State->PendFlag = 0;
  State->PendDelay = 0;
  State->ExtraDelay = 0;
  //State->RegQ16 = 0;

  State->OutputChannel7 = 0;
  for (int j = 0; j < 16; j++)
    State->OutputChannel10[j] = 0;
  State->IndexValue = 0;
  for (int j = 0; j < 1 + NUM_INTERRUPT_TYPES; j++)
    State->InterruptRequests[j] = 0;
  State->InIsr = 0;
  State->SubstituteInstruction = 0;
  State->DownruptTimeValid = 1;
  State->DownruptTime = 0;
  State->Downlink = 0;

  State->NightWatchman = 0;
  State->NightWatchmanTripped = 0;
  State->RuptLock = 0;
  State->NoRupt = 0;
  State->TCTrap = 0;
  State->NoTC = 0;
  State->ParityFail = 0;

  State->WarningFilter = 0;
  State->GeneratedWarning = 0;

  State->RestartLight = 0;
  State->Standby = 0;
  State->SbyPressed = 0;
  State->SbyStillPressed = 0;

  State->NextZ = 0;
  State->ScalerCounter = 0;
  State->ChannelRoutineCount = 0;

  State->DskyTimer = 0;
  State->DskyFlash = 0;
  State->DskyChannel163 = 0;

  State->TookBZF = 0;
  State->TookBZMF = 0;

  State->Trap31A = 0;
  State->Trap31B = 0;
  State->Trap32 = 0;
}

/*
 * yaAGC
 */
#define CORE_SIZE (044 * 02000)
#ifdef __embedded__
// Stuff that's missing.  Figure it out later.
int __errno;
int atexit(void (*function)(void)) { return (0); };
#endif

static void gpt_cb(GPTDriver *gptd)
{
  (void)gptd;
  chSysLockFromISR();
  chThdResumeI(&main_thread_ref, MSG_OK);
  chSysUnlockFromISR();
}

/*
 * Application entry point.
 */
int main(void)
{
  /*
   * System initializations.
   * - HAL initialization, this also initializes the configured device drivers
   *   and performs the board-specific initializations.
   * - Kernel initialization, the main() function becomes a thread and the
   *   RTOS is active.
   */
  halInit();
  chSysInit();

  /*
   * Setup
   */
  lamps_init();
  displays_init();

  /*
   * yaAGC init
   */

  static const GPTConfig agc_gpt_cfg = {
    .frequency = 48000000,
    .callback = gpt_cb,
  };
  gptStart(&GPTD3, &agc_gpt_cfg);

  State = chHeapAlloc(NULL, sizeof(agc_t));
  agc_init(State);

  /*
   * Test
   */
//  displays_set_line(0, 12345);
//  displays_set_line(1, -67890);
//  displays_set_line(2, 13579);
//  displays_set_verb(02);
//  displays_set_noun(46);
//  displays_set_prog(80);
//  chThdSleepMilliseconds(500);


  /*
   * Main loop
   */
  gptStartContinuous(&GPTD3, 562);  // AGC clock is 1024kHz / 12

  uint32_t agc_counter = 0;

  while (true)
  {
    // gptPolledDelay(&GPTD3, 562);
    agc_engine(State);
    if(agc_counter%16==0)  // Clock displays state machine every 16 cycles
    {
      #ifdef TEST
      displays_set_line(2, (agc_counter/16)%100000);
      #endif
      displays_state_machine();
    }
    if(agc_counter%128==0)
    {
      buttons_state_machine();  // Clock buttons state machine
      #ifdef TEST
      test_buttons();
      #endif
    }
#ifdef TEST
    if(agc_counter%8192==0)
    {
      chSysLock();
      lamps_refresh(lamps_set_single(LAMP_COMP_ACTY, 0x0F, 0x00, 0x00));  // Test lamp
      chSysUnlock();
    }
    else if(agc_counter%8192==4096)
    {
      chSysLock();
      lamps_refresh(lamps_set_single(LAMP_COMP_ACTY, 0x00, 0x0F, 0x00));  // Test lamp
      chSysUnlock();
    }
#endif

    agc_counter++;

    chSysLock();
    chThdSuspendTimeoutS(&main_thread_ref, TIME_US2I(2000));  // Long timeout so should be visible when something is wrong...
  }

  return 0;
}

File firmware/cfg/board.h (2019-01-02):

/*
    ChibiOS - Copyright (C) 2006..2016 Giovanni Di Sirio
    Licensed under the Apache License, Version 2.0 (the "License");
    you may not use this file except in compliance with the License.
    You may obtain a copy of the License at
    http://www.apache.org/licenses/LICENSE-2.0
    Unless required by applicable law or agreed to in writing, software
    distributed under the License is distributed on an "AS IS" BASIS,
    WITHOUT WARRANTIES OR CONDITIONS OF ANY KIND, either express or implied.
    See the License for the specific language governing permissions and
    limitations under the License.
*/

/*
    Generated by gen-board.h.py based on cfg/board.yaml
*/

#ifndef _BOARD_H_
#define _BOARD_H_


/*
    Setup for AGC/DSKY Emulator
*/

/*
    Board identifier
*/
#define BOARD_AGC_DSKY_EMULATOR
#define BOARD_NAME                     "AGC/DSKY Emulator"

/*
    Board oscillators-related settings.
*/
#if !defined(STM32_LSECLK)
#define STM32_LSECLK                   0U
#endif

#if !defined(STM32_HSECLK)
#define STM32_HSECLK                   0U
#endif

/*
    Board voltages
    Required for performance limits calculation.
*/
#define STM32_VDD                      330U

/*
    MCU type as defined in the ST header.
*/
#define STM32F072xB

/*
    Other settings.
*/
#define STM32_HSE_BYPASS               
#define STM32_LSEDRV                   (3U << 3U)

/*
    IO pins assignments.
*/
#define GPIOA_NCS_2                    0U
#define GPIOA_NRST_2                   1U
#define GPIOA_USART_TX                 2U
#define GPIOA_USART_RX                 3U
#define GPIOA_PIN4                     4U
#define GPIOA_SPI1_SCK                 5U
#define GPIOA_SPI1_MISO                6U
#define GPIOA_SPI1_MOSI                7U
#define GPIOA_CO5                      8U
#define GPIOA_BR2                      9U
#define GPIOA_BR4                      10U
#define GPIOA_USB_DM                   11U
#define GPIOA_USB_DP                   12U
#define GPIOA_SWDIO                    13U
#define GPIOA_SWCLK                    14U
#define GPIOA_BR3                      15U

#define GPIOB_PIN0                     0U
#define GPIOB_PIN1                     1U
#define GPIOB_NCS_3                    2U
#define GPIOB_BC3                      3U
#define GPIOB_BC1                      4U
#define GPIOB_BC2                      5U
#define GPIOB_BC4                      6U
#define GPIOB_BC5                      7U
#define GPIOB_PIN8                     8U
#define GPIOB_PIN9                     9U
#define GPIOB_NRST_3                   10U
#define GPIOB_CO8                      11U
#define GPIOB_NCS_MPU                  12U
#define GPIOB_SPI2_SCK                 13U
#define GPIOB_SPI2_MISO                14U
#define GPIOB_SPI2_MOSI                15U

#define GPIOC_NCS_1                    0U
#define GPIOC_NRST_1                   1U
#define GPIOC_PIN2                     2U
#define GPIOC_PIN3                     3U
#define GPIOC_PIN4                     4U
#define GPIOC_PIN5                     5U
#define GPIOC_CO1                      6U
#define GPIOC_CO2                      7U
#define GPIOC_CO3                      8U
#define GPIOC_CO4                      9U
#define GPIOC_BR1                      10U
#define GPIOC_PIN11                    11U
#define GPIOC_PIN12                    12U
#define GPIOC_LED_DIN                  13U
#define GPIOC_CO7                      14U
#define GPIOC_CO6                      15U

#define GPIOD_PIN0                     0U
#define GPIOD_PIN1                     1U
#define GPIOD_PIN2                     2U
#define GPIOD_PIN3                     3U
#define GPIOD_PIN4                     4U
#define GPIOD_PIN5                     5U
#define GPIOD_PIN6                     6U
#define GPIOD_PIN7                     7U
#define GPIOD_PIN8                     8U
#define GPIOD_PIN9                     9U
#define GPIOD_PIN10                    10U
#define GPIOD_PIN11                    11U
#define GPIOD_PIN12                    12U
#define GPIOD_PIN13                    13U
#define GPIOD_PIN14                    14U
#define GPIOD_PIN15                    15U

#define GPIOE_PIN0                     0U
#define GPIOE_PIN1                     1U
#define GPIOE_PIN2                     2U
#define GPIOE_PIN3                     3U
#define GPIOE_PIN4                     4U
#define GPIOE_PIN5                     5U
#define GPIOE_PIN6                     6U
#define GPIOE_PIN7                     7U
#define GPIOE_PIN8                     8U
#define GPIOE_PIN9                     9U
#define GPIOE_PIN10                    10U
#define GPIOE_PIN11                    11U
#define GPIOE_PIN12                    12U
#define GPIOE_PIN13                    13U
#define GPIOE_PIN14                    14U
#define GPIOE_PIN15                    15U
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

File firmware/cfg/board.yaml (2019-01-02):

name: AGC/DSKY Emulator
lsefreq: 0
hsefreq: 0
voltage: 3.3
mcutype: STM32F072xB
other:
    STM32_HSE_BYPASS: ~
    STM32_LSEDRV: (3U << 3U) 
default: input, pushpull, starthigh, pullup, highspeed
pins:
    usb_dm : pa11, af0
    usb_dp : pa12, af0
    swdio  : pa13, af0
    swclk  : pa14, af0, pulldown
    led_din: pc13, output, startlow, floating
    
    ncs_1: pc0, output, floating
    ncs_2: pa0, output, floating
    ncs_3: pb2, output, floating
    
    nrst_1: pc1, output, floating
    nrst_2: pa1, output, floating
    nrst_3: pb10, output, floating
    
    usart_tx: pa2, af1, floating
    usart_rx: pa3, af1, floating
    
    spi1_sck : pa5, af0, floating
    spi1_miso: pa6, af0, floating
    spi1_mosi: pa7, af0, floating
    ncs_mpu  : pb12, af0, floating
    spi2_sck : pb13, af0, floating
    spi2_miso: pb14, af0, floating
    spi2_mosi: pb15, af0, floating
    
    co1: pc6, output, startlow, floating
    co2: pc7, output, startlow, floating
    co3: pc8, output, startlow, floating
    co4: pc9, output, startlow, floating
    co5: pa8, output, startlow, floating
    co6: pc15, output, startlow, floating
    co7: pc14, output, startlow, floating
    co8: pb11, output, startlow, floating
    
    br1: pc10, output, startlow, floating
    br2: pa9, output, startlow, floating
    br3: pa15, output, startlow, floating
    br4: pa10, output, startlow, floating
    
    bc1: pb4, pulldown
    bc2: pb5, pulldown
    bc3: pb3, pulldown
    bc4: pb6, pulldown
    bc5: pb7, pulldown

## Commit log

2018-11-04 Add submodules and set up ChibiOS project from example for STM32F072RBT6
    [agc-dsky.kicad_pcb, agc-dsky.sch]
2018-11-07 Add buttons to schematic
    [agc-dsky.sch]
2018-11-07 Add STM32F072RBT6 symbol
2018-11-08 Work on 7 segment displays
    [7-segs.sch, agc-dsky.sch]
2018-11-09 Add SOIC-18-W footprint
    [7-segs.sch, agc-dsky.sch]
2018-11-10 First revision of schematic
    [7-segs.sch, LEDs.sch, agc-dsky.sch]
2018-11-10 Replace 14 segment displays with discrete LEDs and rearrange display driver system
    [7-segs.sch, LEDs.sch, agc-dsky.kicad_pcb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]
2018-11-10 Progress with DSKY board layout
    [agc-dsky.kicad_pcb]
2018-11-10 Work on routing displays
    [7-segs.sch, agc-dsky.kicad_pcb, agc-dsky.sch]
2018-11-10 More work on routing displays
    [agc-dsky.kicad_pcb]
2018-11-10 Add ground pour on bottom layer
    [agc-dsky.kicad_pcb]
2018-11-11 More work on layout
    [agc-dsky.kicad_pcb, agc-dsky.sch]
2018-11-11 More routing of buttons
    [agc-dsky.kicad_pcb, agc-dsky.sch]
2018-11-11 First routing attempt
    [agc-dsky.kicad_pcb]
2018-11-11 First attempt at routing complete
    [LEDs.sch, agc-dsky.kicad_pcb, agc-dsky.sch]
2018-11-11 Add BOM and stickers
2018-11-11 Bridge separated ground plane through ALT LED and add name + date to silkscreen
    [agc-dsky.kicad_pcb]
2018-11-11 Thicken power traces
    [agc-dsky.kicad_pcb]
2018-11-12 Tidy up button references
    [agc-dsky.kicad_pcb]
2018-11-12 Add UART header and imu
    [agc-dsky.kicad_pcb, agc-dsky.sch]
2018-11-12 Generate gerbers
    [agc-dsky-B.Cu.gbl, agc-dsky-B.Mask.gbs, agc-dsky-B.SilkS.gbo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]
2018-11-12 Modify gerber filenames & create zip for dirtypcbs
2018-11-12 Save pcb with gerber info
    [agc-dsky.kicad_pcb]
2018-11-12 Remove drill map
2018-11-29 Fix mistakes in BOM
    [7-segs.sch, agc-dsky.sch]
2018-12-05 Set up board config and update makefile with custom commands
2018-12-06 Add schematic Pdf and update sticker pdf
2018-12-08 Add some yaagc files and first attempt at key matrix driver
2018-12-09 Begin porting over MPU9250 driver from CUSF spalax
2018-12-29 Update buttons driver to signal changes in button state
2018-12-30 Work on buttons & display drivers
2018-12-30 Bug fixes for display & buttons drivers
    [displays.c, main.c, mcp23s08.c]
2018-12-30 Add third party ws2812 driver, reduce clock speed to 24MHz to allow zero wait state for accurate timing
2018-12-31 Update ws2812 driver and add lamps driver
2019-01-01 Fix bugs for display & button threads working in parallel
    [board.h, board.yaml, displays.c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]
2019-01-02 Work on lamp driver
2019-01-02 First revision of working blocking WS2812B driver
2019-01-03 Add to lamps driver and begin integrating yaAGC
2019-01-05 Small bugfixes and optimisations
    [main.c]

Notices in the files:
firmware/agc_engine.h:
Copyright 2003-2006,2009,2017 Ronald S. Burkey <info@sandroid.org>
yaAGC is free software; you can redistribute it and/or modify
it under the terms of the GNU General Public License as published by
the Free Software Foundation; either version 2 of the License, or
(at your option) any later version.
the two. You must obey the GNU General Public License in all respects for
